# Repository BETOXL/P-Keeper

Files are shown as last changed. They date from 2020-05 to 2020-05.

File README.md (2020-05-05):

# P-Keeper
[thepkeeper.wordpress.com](https://thepkeeper.wordpress.com/)
[Descarga OneDrive](https://onedrive.live.com/?cid=d52501074a44db40&id=D52501074A44DB40%211425&authkey=!ACjRxlZXIObkq4Y)
## Respirador artificial para el COVID-19, Artificial respirator for COVID-19

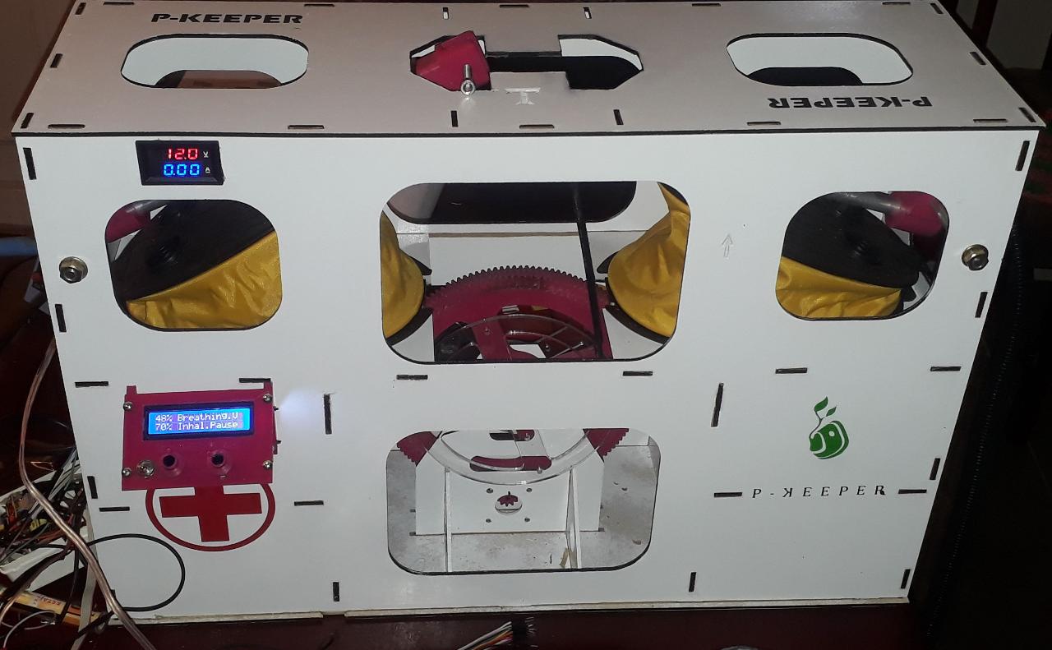
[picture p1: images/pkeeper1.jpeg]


# Que es P-Keeper?

Es un sistema de respiración asistida para contingencias, diseñado para ser producido en masa por cualquier empresa o emprendedor y con excelentes materiales disponibles pensados para durar pero no homologado ni avalado por ningún organismo de la salud a nivel mundial. Fue concebido para ayudar en la pandemia mundial del COVID-19 y en caso de extrema emergencia.

# Como Funciona?
## Todo respirador debe cumplir con los parametros:

- Volumen de ingreso de aire: de 6 a 8ml/kg.
- Presión de ingreso de aire: determinado por el medico.
- Frecuencia respiratoria: 10 a 20rpm regulable o programable
- Pausa entre inhalación y exhalación regulable.
- Posibilidad de extracción de aire si el paciente no puede exhalar por sus medios.

# Para lograr todos estos parametros P-KEEPER utiliza:

- 2 fuelles de 5lts de volumen máximo que pueden ser regulados hasta los 200ml, los cuales sirven: 1 para el ingreso de aire y otro para extracción del aire en el caso que el paciente no puede hacerlo por sus medios pero puede operar con solo 1 fuelle para la inhalación.
- 2 motores paso a paso, 1 capaz de aportar movimiento continuo las 24hs por 80 días antes de una revisión en sus rodamientos y el otro como sistema redundante de backup el cual está montado sobre el mismo eje y mide en todo momento el esfuerzo que el motor 1 realiza y cuando se sale de parámetros, se hace una conmutación para apagar un motor y arrancar el otro de manera instantánea y en la misma posición, mostrando con un led que el motor 1 está fuera de servicio .
- Sistema de control electrónico análogo para regular parámetros con simples potenciómetros, que regulan el tiempo de giro de los motores y frecuencias internas que permiten que el motor realice pausas en algún momento del recorrido.
- Ruedas de accionamientos.
- Levas de accionamiento regulables sobre las ruedas para poder regular el volumen de aire.
- Válvulas tipo diafragma para las mangueras y conexiones standard para cualquier manguera de respirador en el mercado.
- Cámara mezcladora de aire y oxigeno en el aspirado del fuelle.

# Funcionamiento?

El motor paso a paso, mueve por unos engranes y poleas la rueda de transmisión que tiene sujetas las levas de accionamiento que mueven los fuelles, uno sube cuando el otro baja y por ende, uno inyecta aire y el otro lo extrae del paciente, con unos potenciómetros se pueden regular las velocidades y pausas pero a su vez con tan solo un ajuste mecánico en la rueda de transmisión se puede graduar el volumen de aire que se quiere inyectar y extraer del paciente. También posee sistema de bateria de 12v que permiten mantener el funcionamiento por al menos 12hs sin conexión a la red eléctrica.

# Esquema Arduino

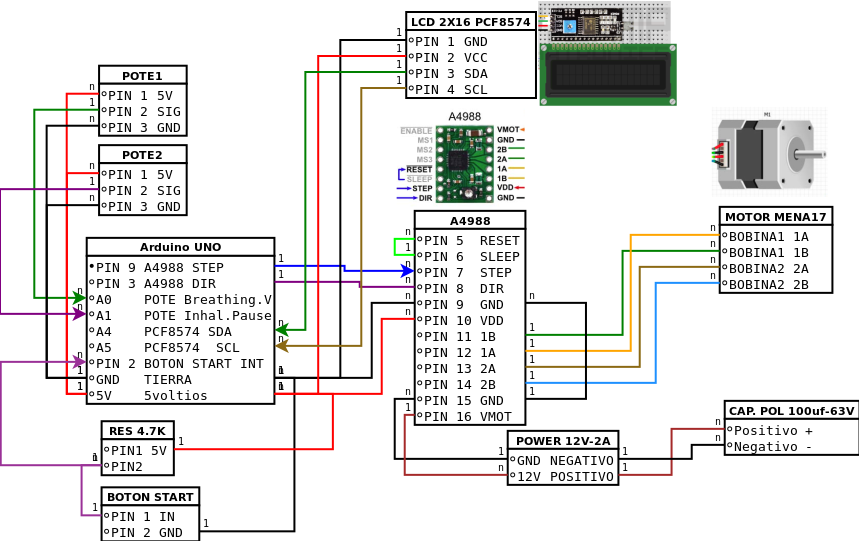
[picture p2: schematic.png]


# Tu donacion es importante.

MP 50 Donate Button (https://www.mercadopago.com.ar/checkout/v1/redirect?pref_id=51834467-b68b30ba-cf1f-4a6f-ab7c-61168bebfa8b)

MP 100 Donate Button (https://www.mercadopago.com.ar/checkout/v1/redirect?pref_id=51834467-e1bbad45-b30b-48c3-a3cd-1f066ffff9e0)

MP 500 Donate Button (https://www.mercadopago.com.ar/checkout/v1/redirect?pref_id=51834467-1f20acdd-35a0-4b01-af16-70227fb802b1)

MP 1000 Donate Button (https://www.mercadopago.com.ar/checkout/v1/redirect?pref_id=51834467-9a8c5bf6-71cb-4cd0-aa24-7966df1e3508)

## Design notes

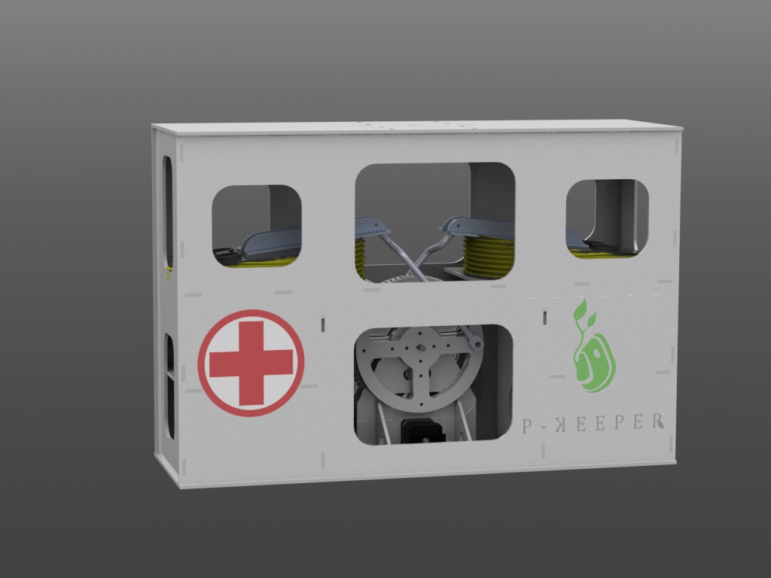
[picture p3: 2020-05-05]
Plans3Dfiles/full.JPG

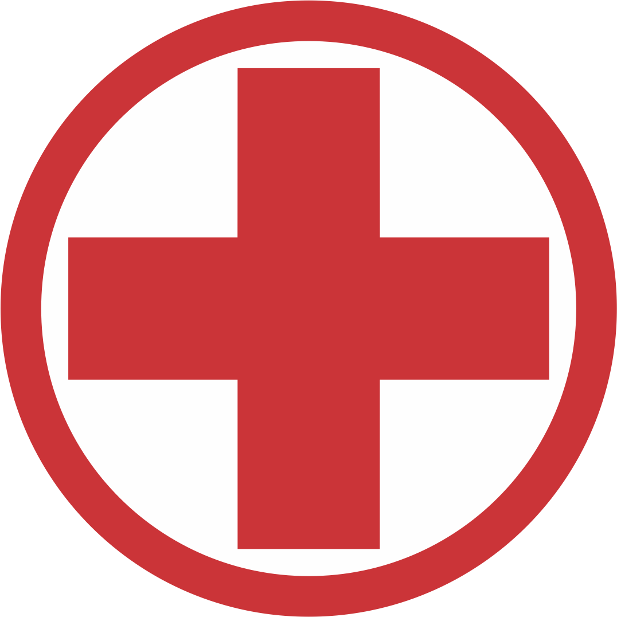
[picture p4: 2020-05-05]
Plans3Dfiles/CALCOS.png

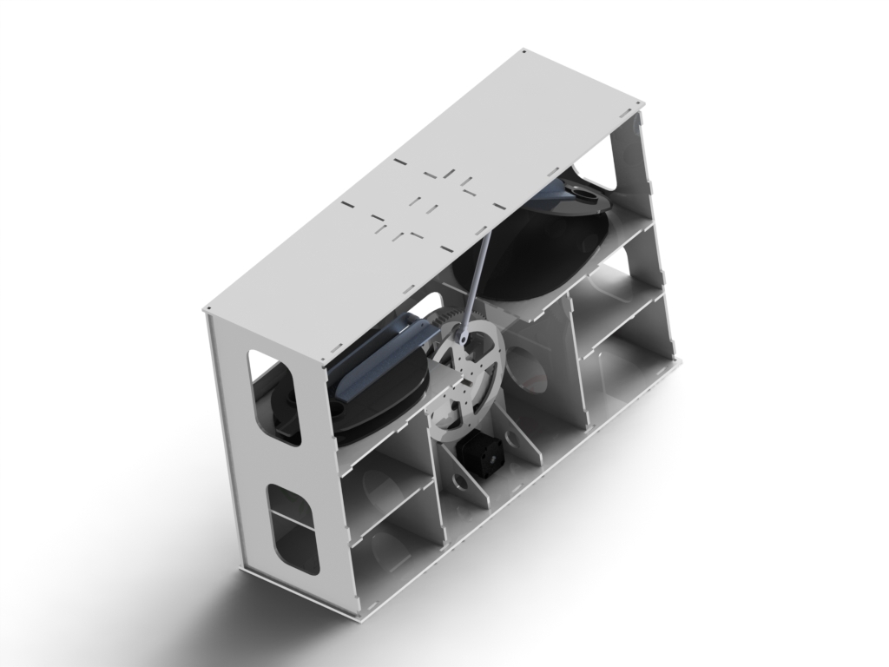
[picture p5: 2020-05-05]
Plans3Dfiles/vista.JPG

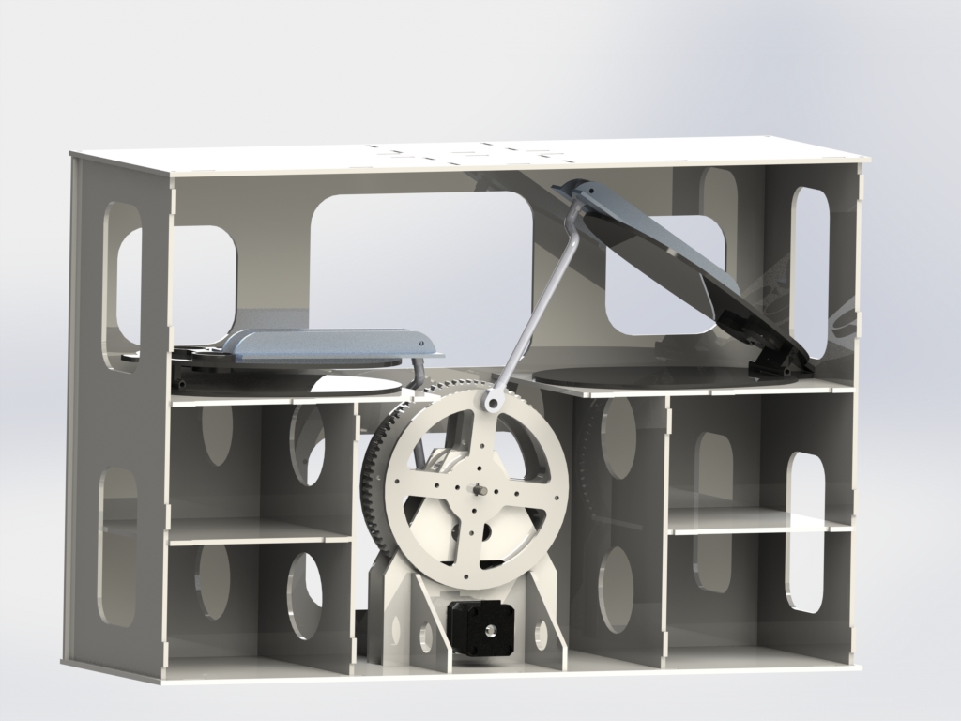
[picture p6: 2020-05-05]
Plans3Dfiles/Front.JPG

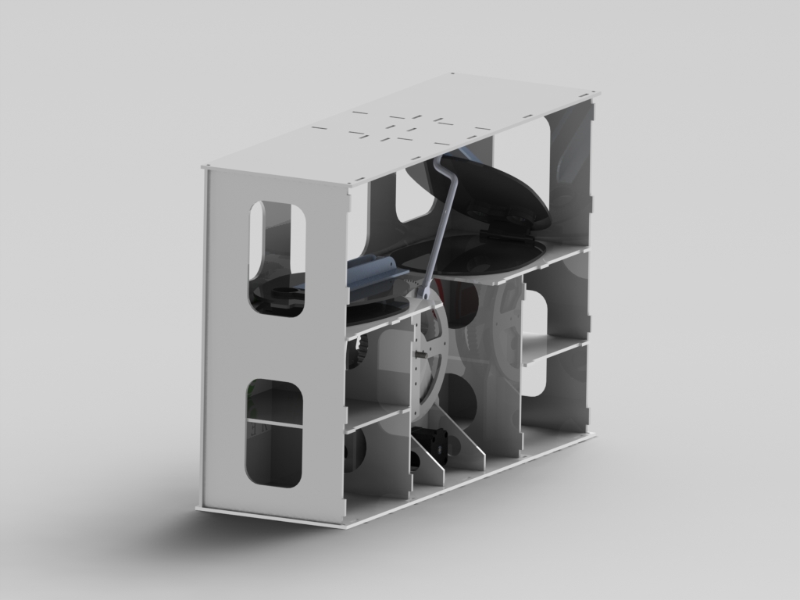
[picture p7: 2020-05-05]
Plans3Dfiles/vista 2.JPG

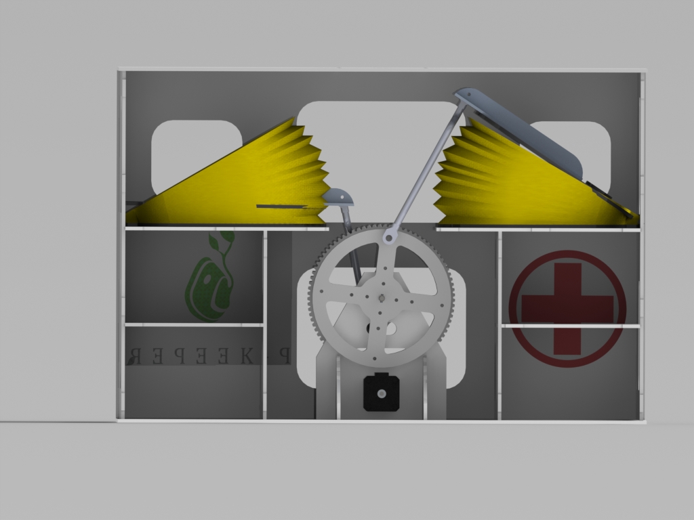
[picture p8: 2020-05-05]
Plans3Dfiles/with bellows.JPG

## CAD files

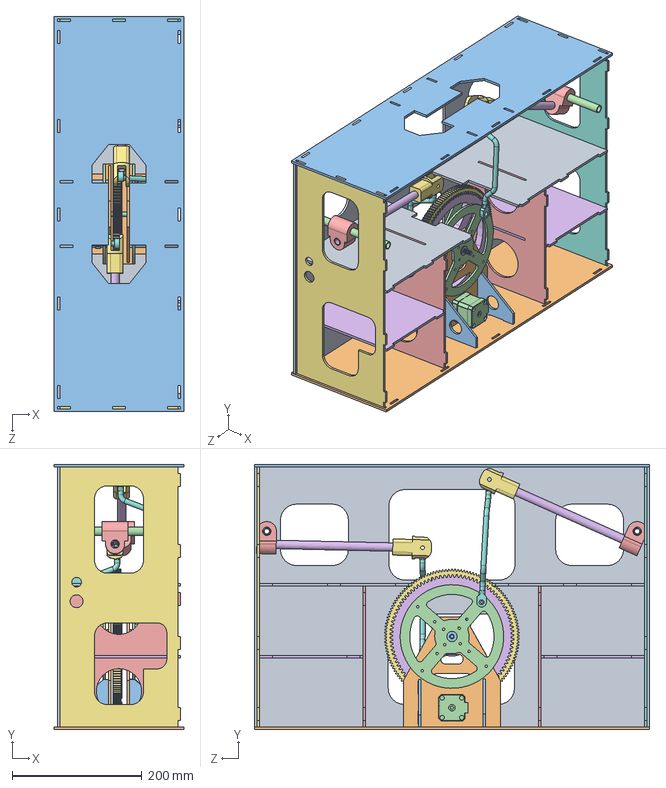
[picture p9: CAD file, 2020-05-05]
Plans3Dfiles/final assembly.SLDASM
200.0 x 410.0 x 610.0 mm
Front and Back Wall
Motor Front Wall x 2
Motor Side Wall x 4
nema 17 x 2
secondary gear 10t
main gear 94t
main gear 137t over 94t
main shaft
Shaft PIN x 3
bearing DIN 625 - 627 - 8,DE,NC,8_68 x 2
washer x 4
Actuator Wheel x 2
MIddle Floor Support x 2
Electronic's Floor x 2
Side2
Sides
Middle Floor x 2
Floor 2
Floor 1
support actuator tube x 2
Actuators Support x 2
actuator tube x 2
clevis x 2
Actuator Rod x 2

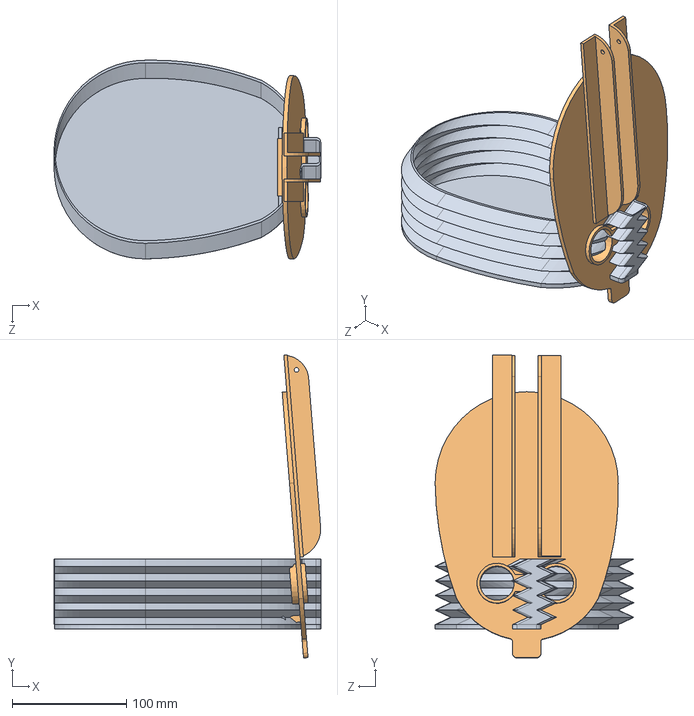
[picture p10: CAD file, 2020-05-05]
Plans3Dfiles/Assem2.SLDASM
233.2 x 264.7 x 173.7 mm
tapa de fuelle
tapa sup de fuelle

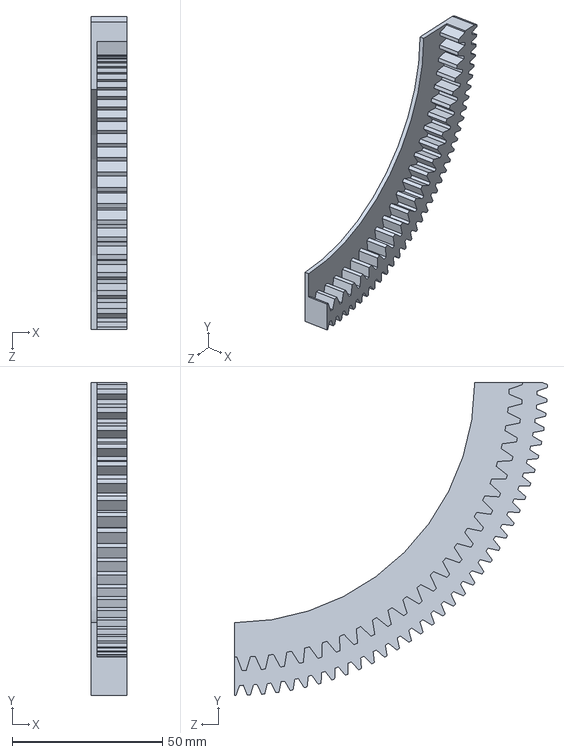
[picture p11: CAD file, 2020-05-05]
Plans3Dfiles/main gear 137t over 94t part3.SLDPRT
12.0 x 104.2 x 104.2 mm

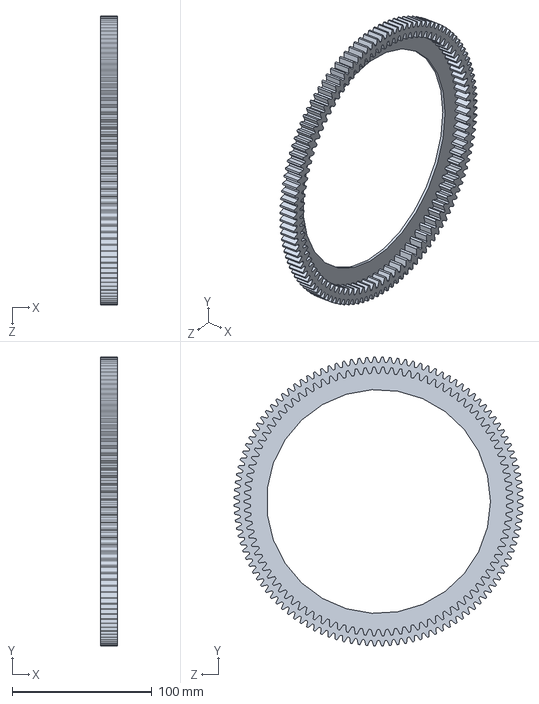
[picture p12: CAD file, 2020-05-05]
Plans3Dfiles/DIN - Spur gear 1.75M 116T 20PA 12FW ---S116A75H50L4N main gear 4.SLDPRT
12.0 x 206.5 x 206.5 mm

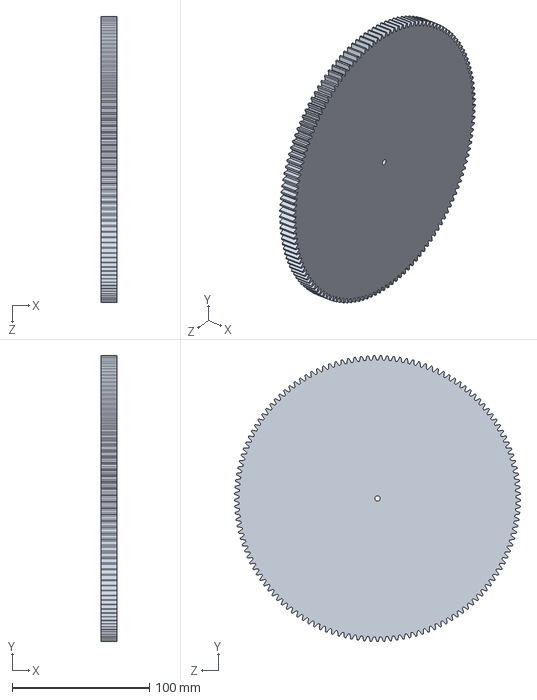
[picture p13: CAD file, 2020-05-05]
Plans3Dfiles/main gear 137t.SLDPRT
12.0 x 208.5 x 208.5 mm

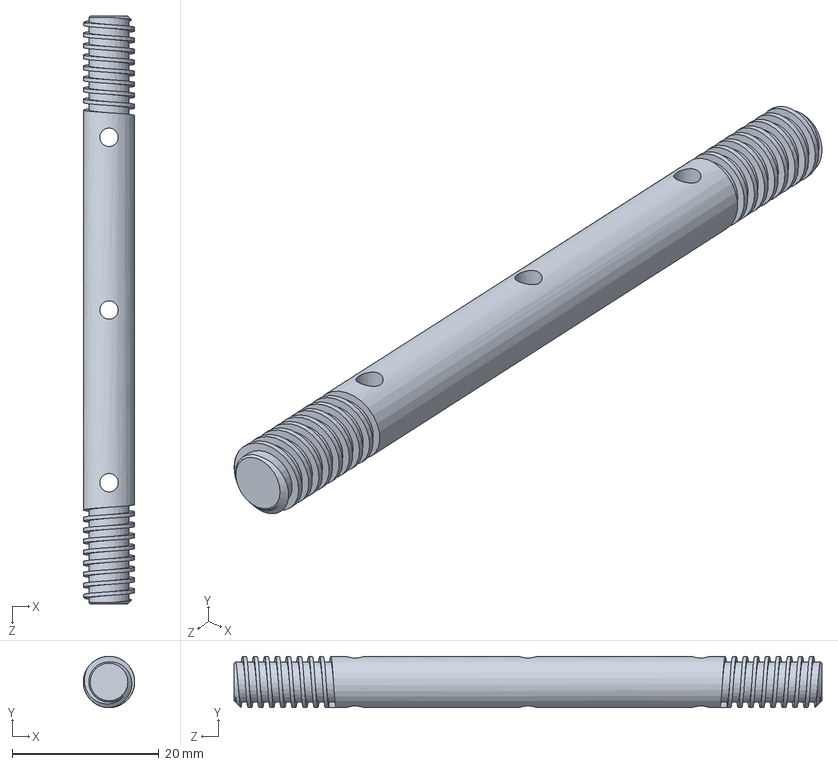
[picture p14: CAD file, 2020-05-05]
Plans3Dfiles/main shaft.SLDPRT
7.00 x 7.00 x 80.0 mm

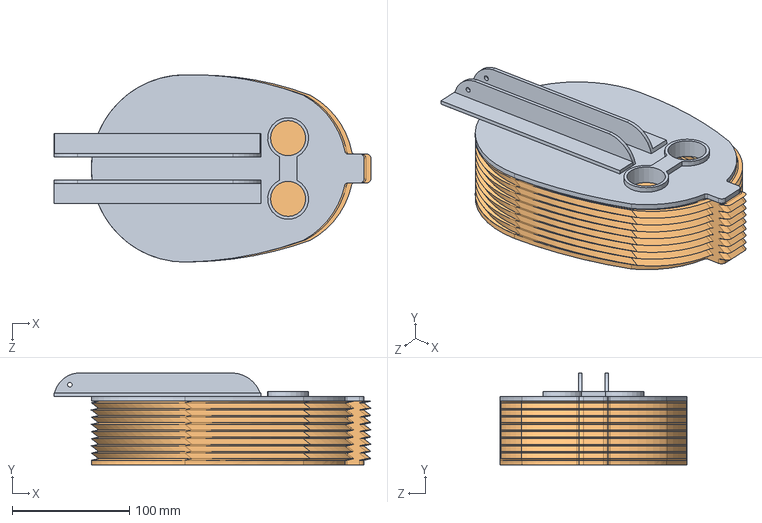
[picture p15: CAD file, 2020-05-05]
Plans3Dfiles/Assem fuelle2.SLDASM
270.8 x 78.6 x 160.0 mm
tapa sup de fuelle
tapa de fuelle

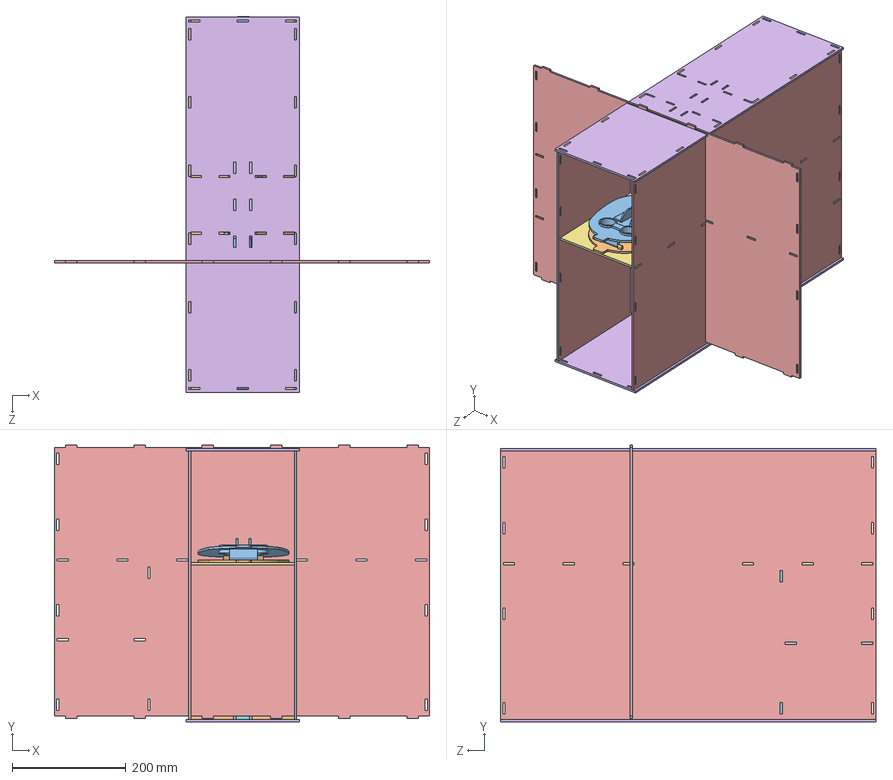
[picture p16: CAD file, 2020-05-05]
Plans3Dfiles/Respirator.SLDASM
660.0 x 486.2 x 660.9 mm
frente de motor x 2
lateral de motor x 4
nema 17 x 2
rueda x 2
piso 2 x 2
lateral x 2
entrepiso x 2
soporte de entrepiso
piso para electronica
tapa de fuelle x 2
tapa sup de fuelle x 2
bastago x 2

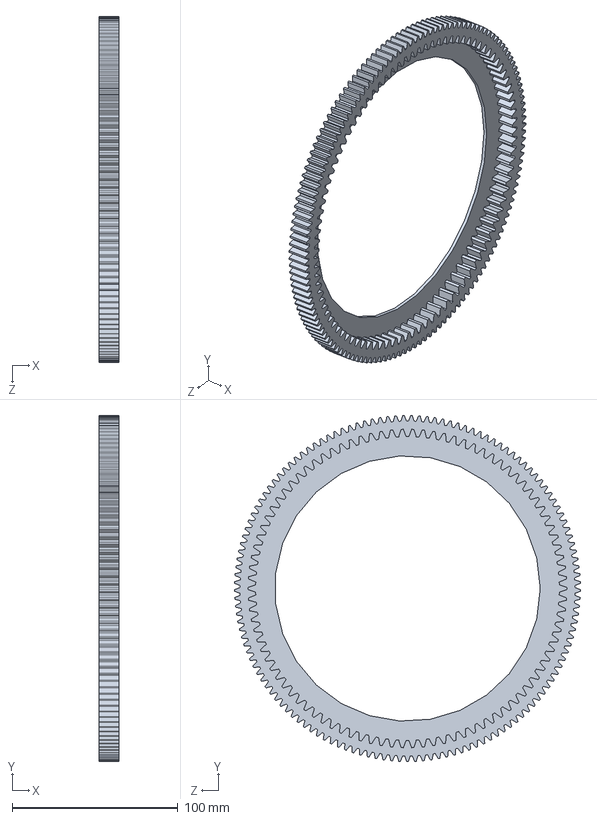
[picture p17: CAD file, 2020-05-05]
Plans3Dfiles/main gear 137t over 94t.SLDPRT
12.0 x 208.5 x 208.5 mm

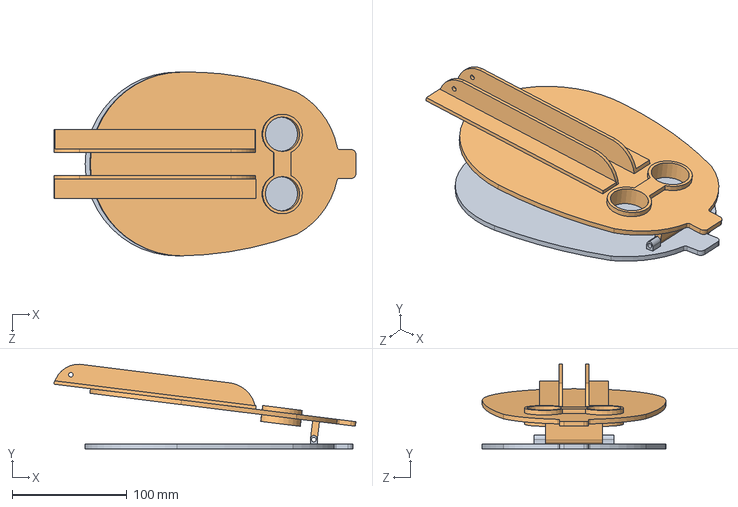
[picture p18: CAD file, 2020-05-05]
Plans3Dfiles/fuelle.SLDASM
263.0 x 73.6 x 160.0 mm
tapa de fuelle
tapa sup de fuelle

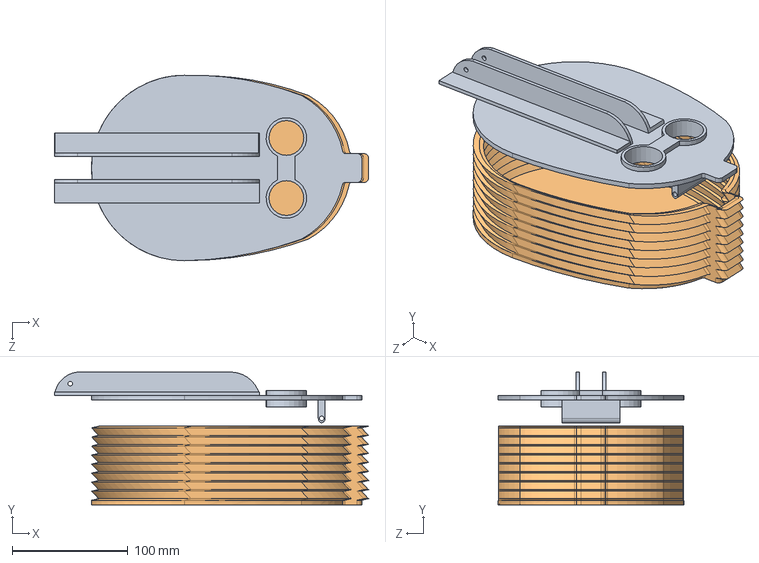
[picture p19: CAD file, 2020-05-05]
Plans3Dfiles/Assem fuelle1.SLDASM
270.8 x 114.6 x 160.0 mm
tapa sup de fuelle
tapa de fuelle

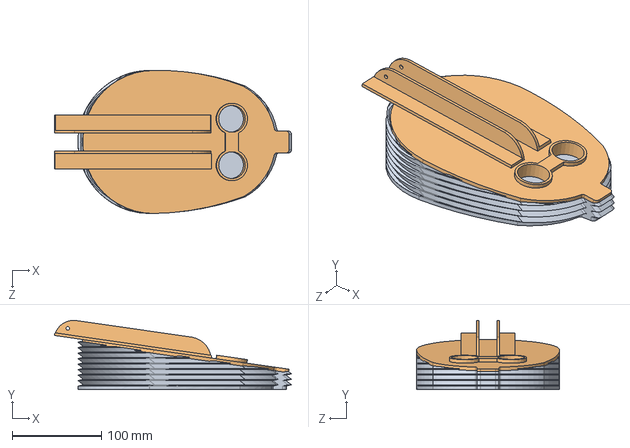
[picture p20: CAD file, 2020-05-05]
Plans3Dfiles/Final bellows.SLDASM
265.1 x 77.6 x 160.0 mm
tapa de fuelle2
tapa sup de fuelle

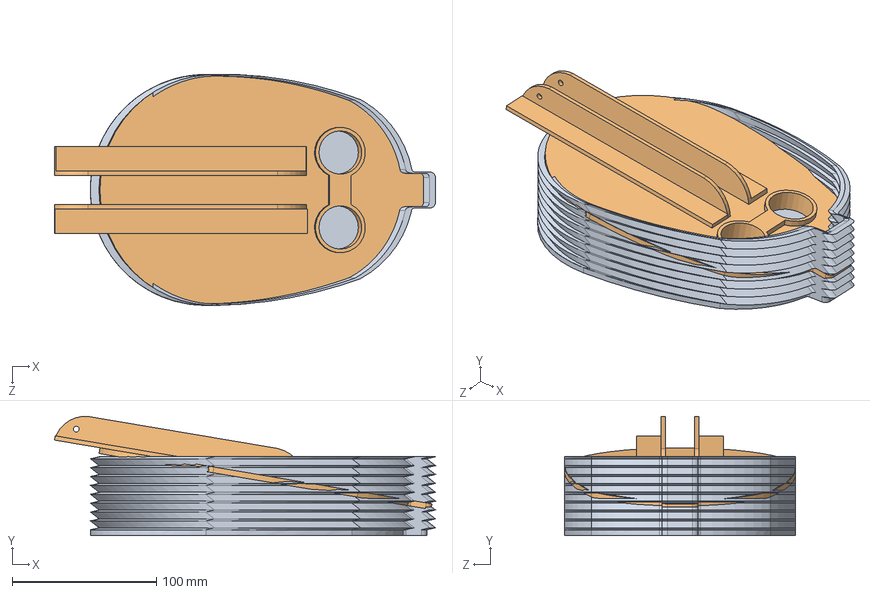
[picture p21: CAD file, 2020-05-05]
Plans3Dfiles/Assem fuelle3.SLDASM
263.7 x 82.5 x 160.0 mm
tapa de fuelle
tapa sup de fuelle

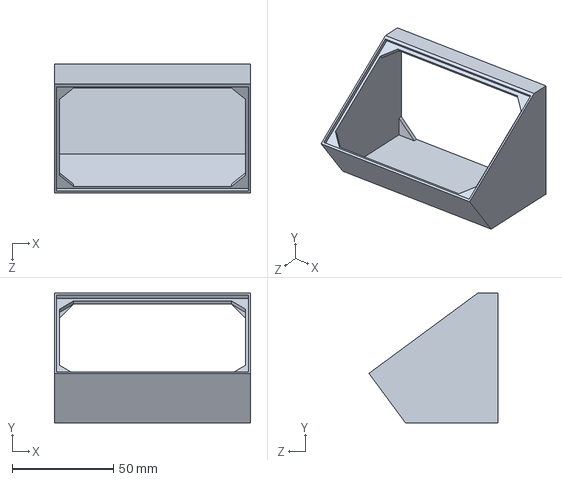
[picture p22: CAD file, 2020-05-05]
Plans3Dfiles/display main body.SLDPRT
97.0 x 64.3 x 63.9 mm

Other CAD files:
Plans3Dfiles/main gear 137t over 94t part4.SLDPRT
Plans3Dfiles/total assy.SLDASM
Plans3Dfiles/Respirator2.SLDASM
Plans3Dfiles/main gear 137t over 94t part1.SLDPRT
Plans3Dfiles/3D files P-Keeper/boquilla con tuerca.STL
Plans3Dfiles/3D files P-Keeper/conector Y comun.STL
Plans3Dfiles/3D files P-Keeper/cuerpo de Camara Y.STL
Plans3Dfiles/3D files P-Keeper/niple conector de manguera.STL
Plans3Dfiles/3D files P-Keeper/tapa de camara.STL
Plans3Dfiles/3D files P-Keeper/tuerca de camara Y.STL
Plans3Dfiles/Actuator Rod.SLDDRW
Plans3Dfiles/Actuator Rod.SLDPRT
Plans3Dfiles/Actuator Support.STL
Plans3Dfiles/Actuator Wheel.SLDDRW
Plans3Dfiles/Actuator Wheel.SLDPRT
Plans3Dfiles/Actuators Support.SLDPRT
Plans3Dfiles/Chamber Top.SLDPRT
Plans3Dfiles/Electronic's Floor.SLDDRW
Plans3Dfiles/Electronic's Floor.SLDPRT
Plans3Dfiles/Floor 1.SLDPRT
Plans3Dfiles/Floor 2.SLDPRT
Plans3Dfiles/Floor Wall.SLDDRW
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

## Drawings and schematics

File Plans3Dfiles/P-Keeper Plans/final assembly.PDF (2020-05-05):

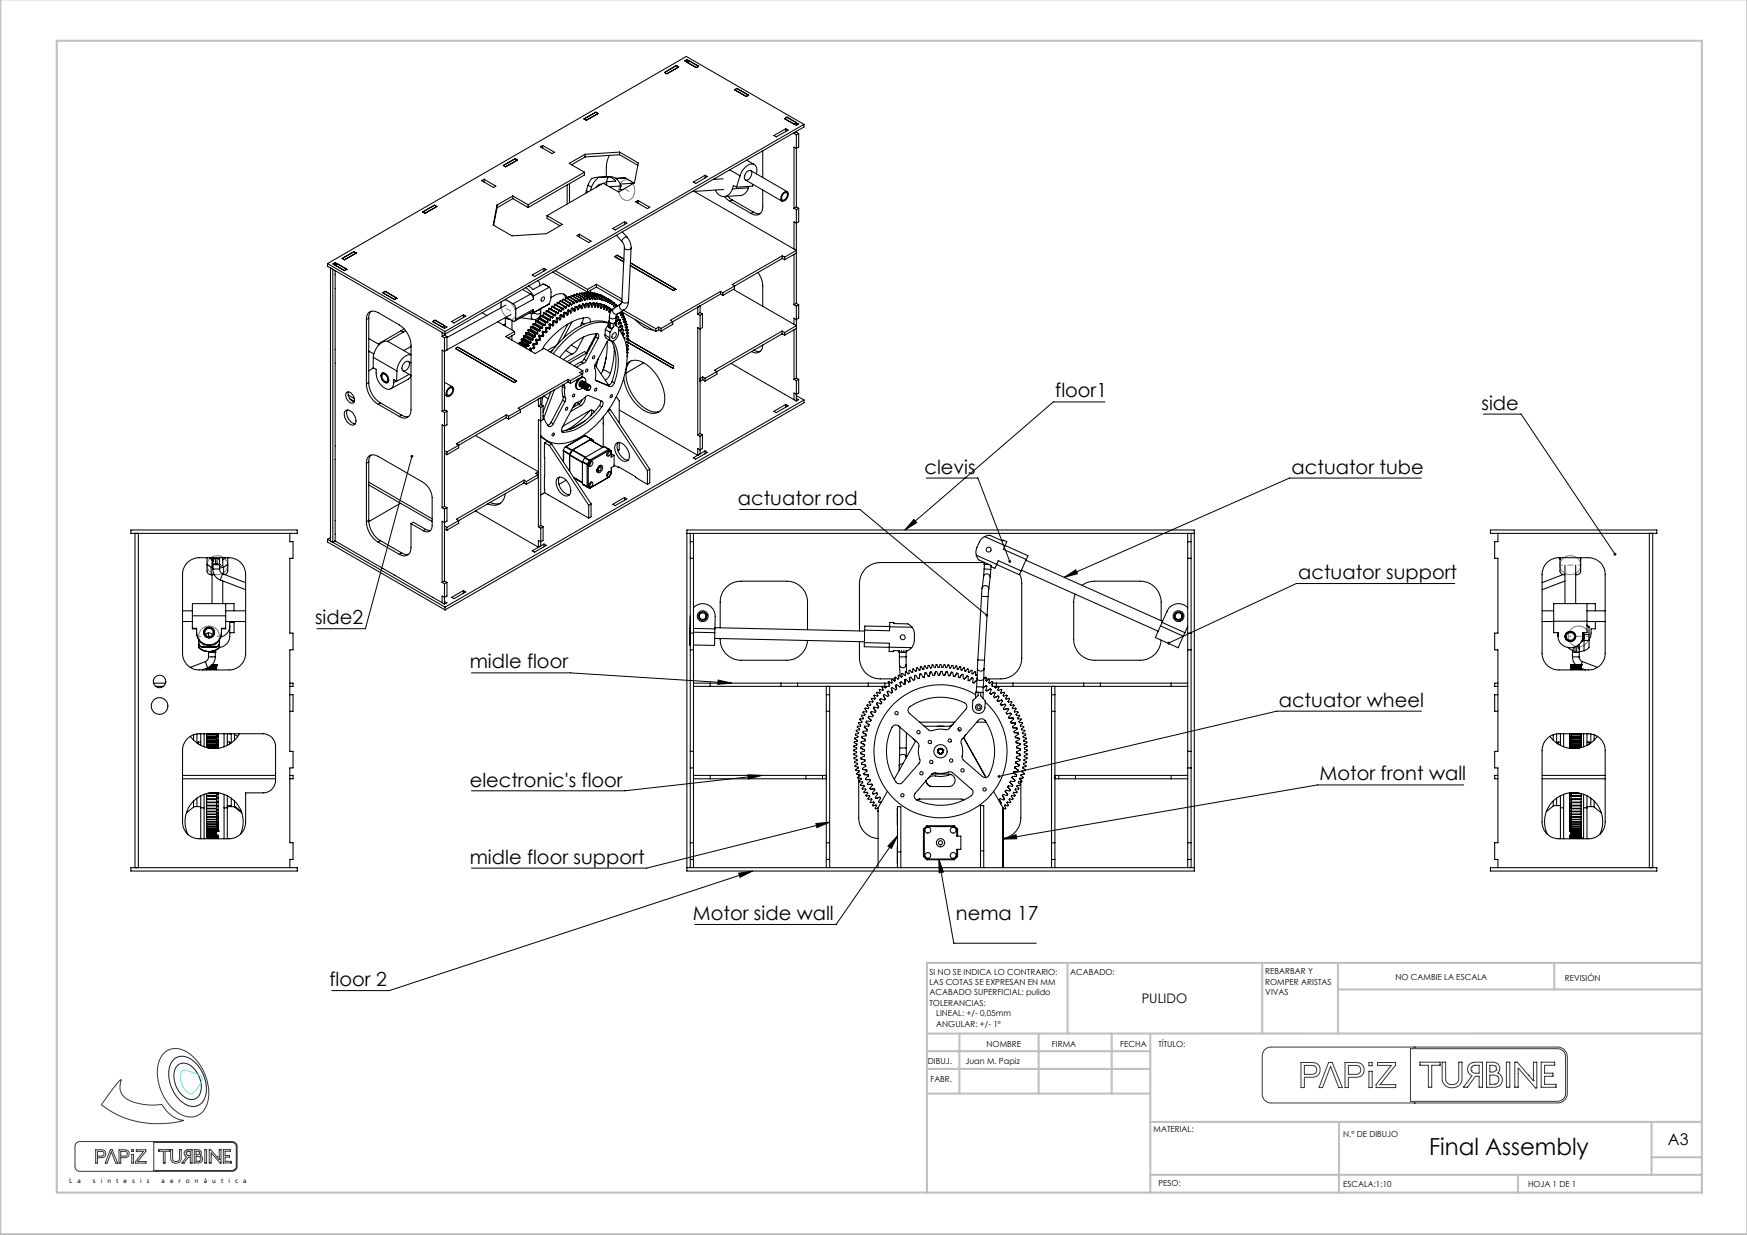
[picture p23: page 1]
actuator tube; actuator support; actuator wheel; nema 17; electronic's floor; midle floor; floor 2; actuator rod; Final Assembly; ESCALA:1:10; HOJA 1 DE 1; N.º DE DIBUJO; NO CAMBIE LA ESCALA; REVISIÓN; REBARBAR Y ROMPER ARISTAS; SI NO SE INDICA LO CONTRARIO:; ACABADO:

Motor front wall

midle floor support

Motor side wall

LAS COTAS SE EXPRESAN EN MM
ACABADO SUPERFICIAL: pulido
TOLERANCIAS:
LINEAL: +/- 0,05mm
ANGULAR: +/- 1º

NOMBRE | FIRMA | FECHA | TÍTULO:

DIBUJ. | Juan M. Papiz
FABR.

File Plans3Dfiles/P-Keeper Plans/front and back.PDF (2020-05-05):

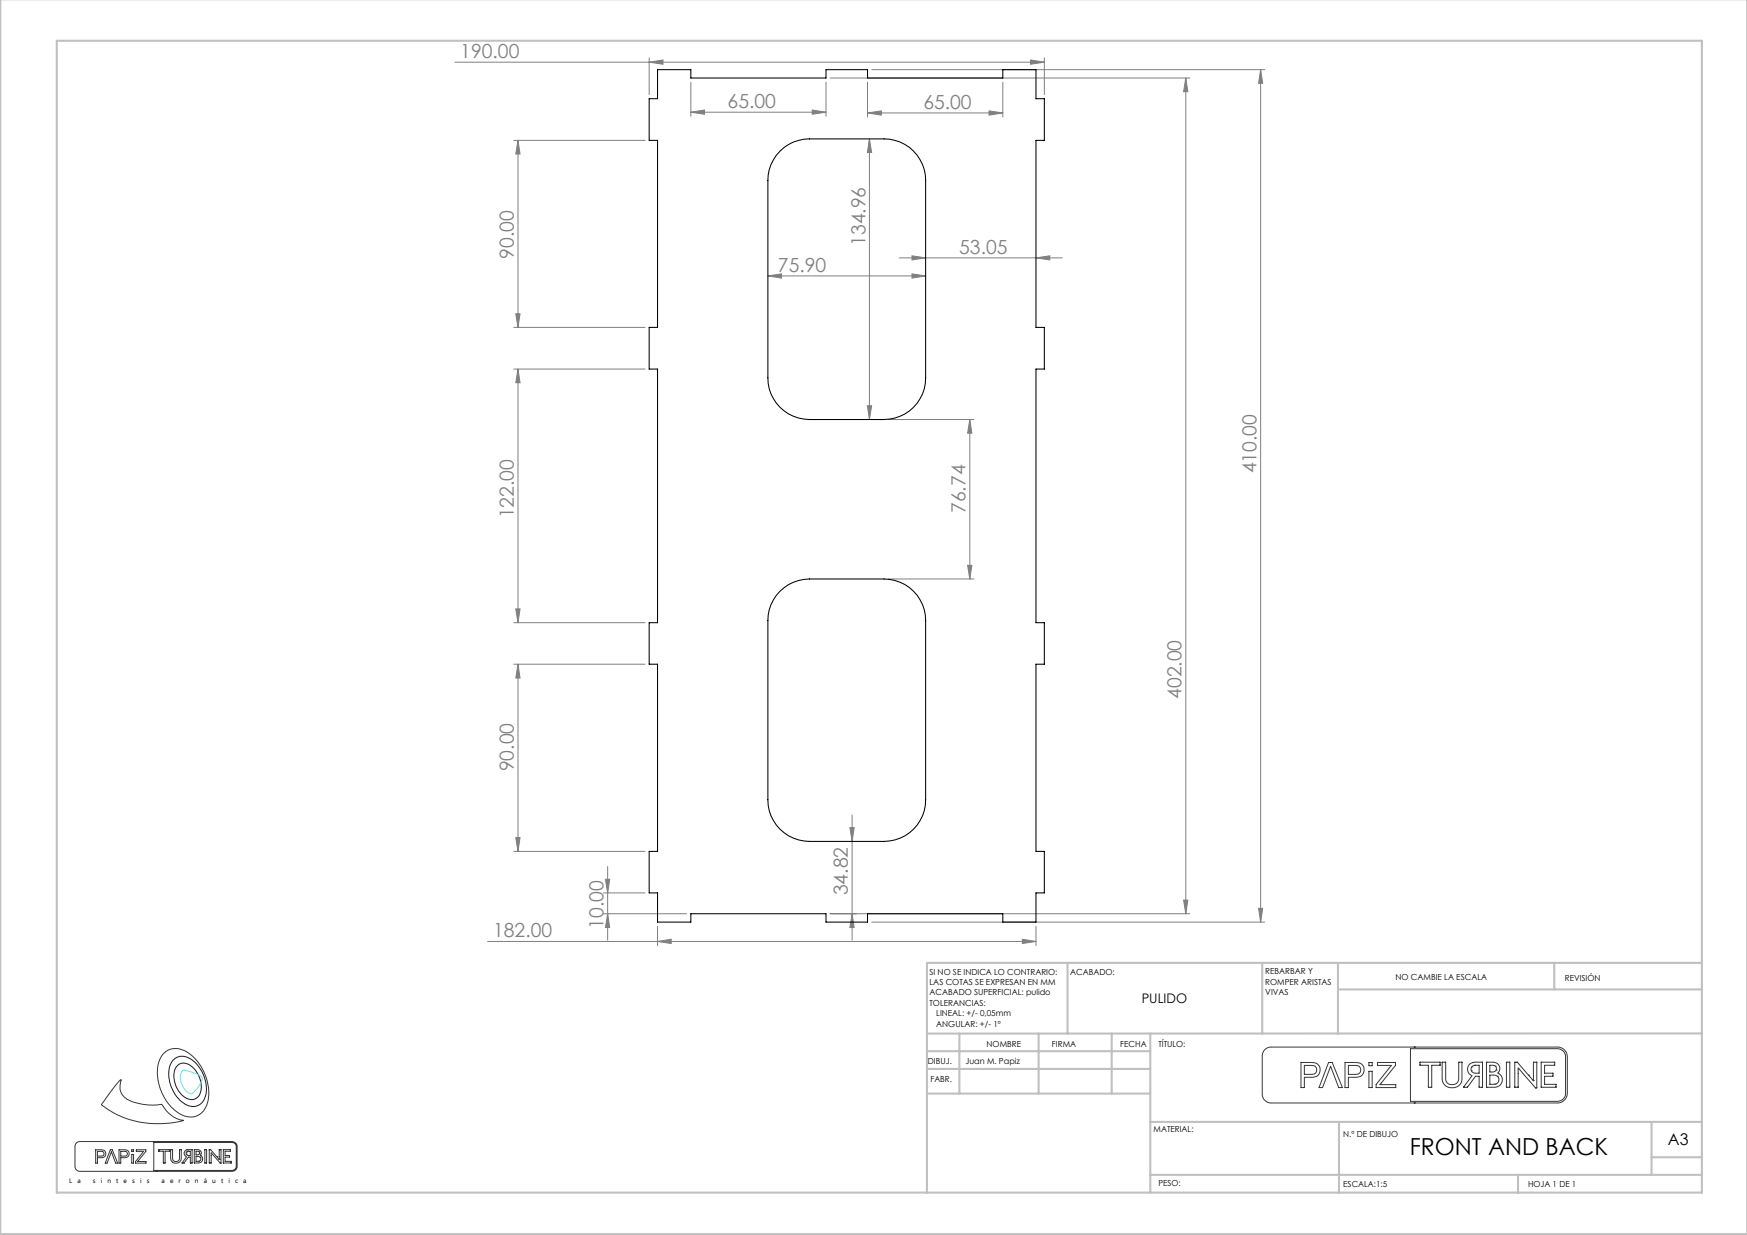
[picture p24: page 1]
ESCALA:1:5; HOJA 1 DE 1; NO CAMBIE LA ESCALA; REVISIÓN; REBARBAR Y ROMPER ARISTAS; SI NO SE INDICA LO CONTRARIO:; ACABADO:

LAS COTAS SE EXPRESAN EN MM
ACABADO SUPERFICIAL: pulido
TOLERANCIAS:
LINEAL: +/- 0,05mm
ANGULAR: +/- 1º

NOMBRE | FIRMA | FECHA | TÍTULO:

DIBUJ. | Juan M. Papiz
FABR.

N.º DE DIBUJO
FRONT AND BACK

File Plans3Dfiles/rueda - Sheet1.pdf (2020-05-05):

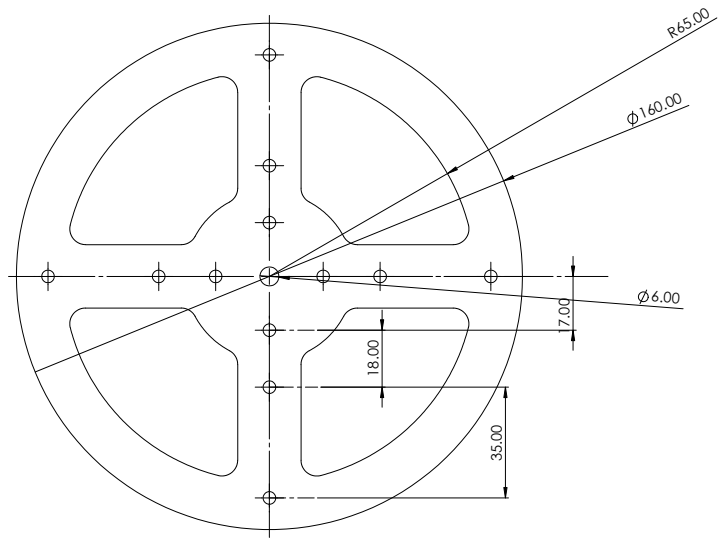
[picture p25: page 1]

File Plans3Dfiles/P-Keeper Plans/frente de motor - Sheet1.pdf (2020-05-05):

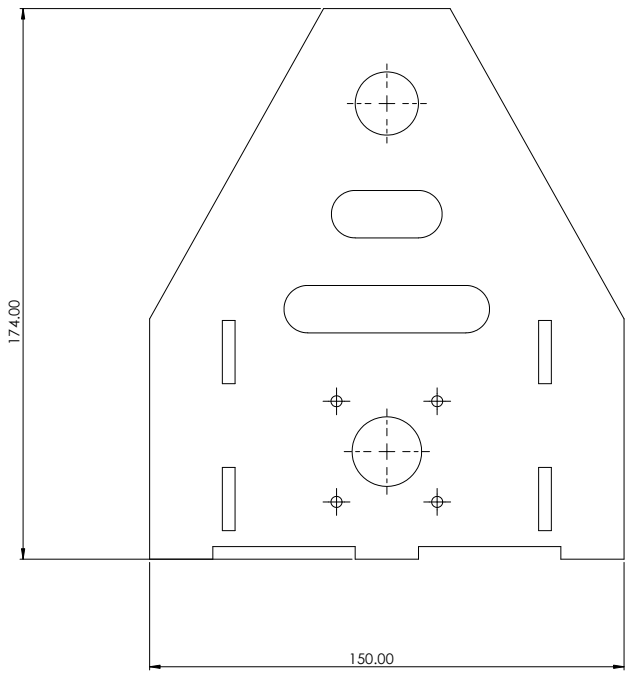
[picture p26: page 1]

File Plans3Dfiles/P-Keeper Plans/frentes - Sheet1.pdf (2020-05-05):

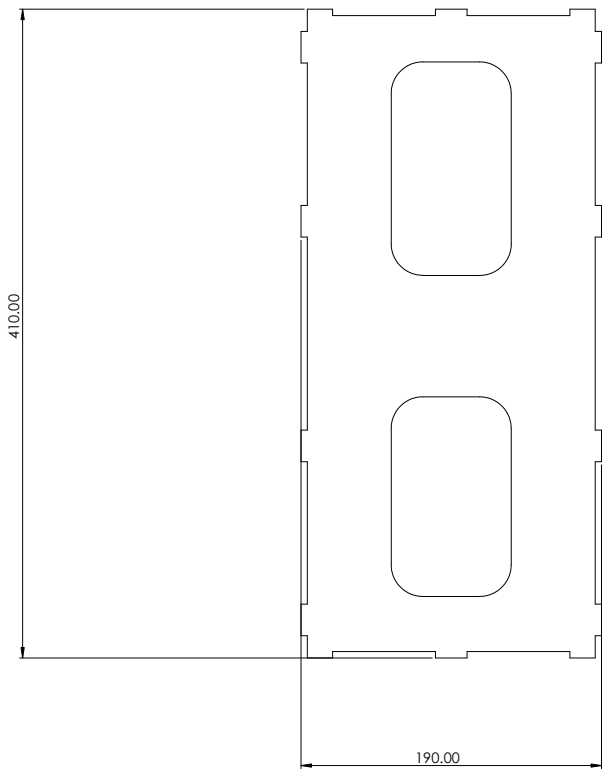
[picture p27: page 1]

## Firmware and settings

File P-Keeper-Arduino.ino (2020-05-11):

/* Control velocidad y sentido giro de motor PaP con pololu A4988 
 *  2020 - P-keeper
 */
//https://bitbucket.org/fmalpartida/new-liquidcrystal/downloads/
#include <Wire.h>			// libreria de comunicacion por I2C
#include <LCD.h>			// libreria para funciones de LCD
#include <LiquidCrystal_I2C.h>		// libreria para LCD por I2C

int steps = 9;       // pin step 9
int direccion = 3;   // pin direccion 3
int potenciometro;   // lectura del potenciometro
int potenciometro2; // lectura del potenciometro2
int botonStart = 2;       // pin pulsador PIN2
int valueBtnStart = 0;
bool running = false;
//int boton = 7;       // pin pulsador 7
int porRetVeloc;
int porRetInaExa;
int analogico0;
int analogico1;
LiquidCrystal_I2C lcd (0x27, 2, 1, 0, 4, 5, 6, 7); // DIR, E, RW, RS, D4, D5, D6, D7

void setup() {
  // inicializamos pin como salidas.
  pinMode(steps, OUTPUT); 
  pinMode(direccion, OUTPUT); 
  pinMode(botonStart, INPUT);
  // Indicar a la libreria que tenemos conectada una pantalla de 16x2
  lcd.setBacklightPin(3,POSITIVE);	// puerto P3 de PCF8574 como positivo
  lcd.setBacklight(HIGH);		// habilita iluminacion posterior de LCD
  lcd.begin(16, 2);			// 16 columnas por 2 lineas para LCD 1602A
  lcd.clear();			// limpia pantalla
  lcd.print("The P-Keeper"); // Enviar el mensaje
  lcd.setCursor(0, 1);
  lcd.print(".wordpress.com");
}

void loop() {
    valueBtnStart = digitalRead(botonStart);  //lectura digital de pin
    if (valueBtnStart == LOW) {
      delay(100);
      if (valueBtnStart == LOW) {        //control anti Rebote
        running = true;             // toggle running variable
        lcd.clear();
      }
    }
      
    if (running == true) {
      analogico0 = analogRead(A0);     // leemos el potenciometro en el puerto A0
      porRetVeloc = map(analogico0, 0, 1023, 100, 0);
      potenciometro = map(analogico0,0,1023,700,4500);  // adaptamos el valor leido a un retardo 700microSeg y 4500microSeg
      analogico1 = analogRead(A1);     // leemos el potenciometro en el puero A1
      porRetInaExa = map(analogico1, 0, 1023, 0, 100);
      potenciometro2 = map(analogico1,0,1023,800,2600);  // adaptamos el valor leido a un retardo de 0.8 a 2.6seg
      //int sentido = digitalRead(boton);    // leemos el boton de direccion
      digitalWrite(direccion, LOW);    // cambiamos de dirección segun pulsador
      //PANTALLA
      lcd.setCursor(0, 0);		// ubica cursor en columna 0 y linea 0
      lcd.print(porRetVeloc);  // Valor pauda en microsegundo
      lcd.print("% Breathing.V");
      lcd.setCursor(0, 1);
      lcd.print(porRetInaExa);  // Valor pauda en microsegundo
      lcd.print("% Inhal.Pause");
      //INAHALACION
      for (int x = 0; x < 1370 ; x++) {      // 200 pasos para 180° y como tiene un reductor se necesita 1370 pasos para 180°
        digitalWrite(steps, HIGH);         // Aqui generamos un flanco de bajada HIGH - LOW
        delayMicroseconds(5);              // Pequeño retardo para formar el pulso en STEP
        digitalWrite(steps, LOW);         // y el A4988 de avanzara un paso el motor
        delayMicroseconds(potenciometro); // generamos un retardo con el valor leido del potenciometro
      }
      delay(potenciometro2); // retardo de inahalacion y exalacion
      //EXALACION
      for (int x = 0; x < 1370 ; x++) {      // 200 pasos para 180° y como tiene un reductor se necesita 1370 pasos para 180°
        digitalWrite(steps, HIGH);         // Aqui generamos un flanco de bajada HIGH - LOW
        delayMicroseconds(5);              // Pequeño retardo para formar el pulso en STEP
        digitalWrite(steps, LOW);         // y el A4988 de avanzara un paso el motor
        delayMicroseconds((potenciometro + 800)); // generamos un retardo con el valor leido del potenciometro Y LE sumamos 800MICROSEGUNDOS
      }
      delay(potenciometro2); // retardo de inahalacion y exalacion
    }
}

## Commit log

2020-05-04 arduino code is loaded and the file is edited read
2020-05-05 se carga titulos y se corrige error de int
    [P-Keeper-Arduino.ino]
2020-05-05 add file 3d and plans
    [Actuator Rod.SLDDRW, Actuator Rod.SLDPRT, Actuator Support.STL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]
2020-05-11 Corrección de error de apagados aleatorios del eq.
    [P-Keeper-Arduino.ino]
